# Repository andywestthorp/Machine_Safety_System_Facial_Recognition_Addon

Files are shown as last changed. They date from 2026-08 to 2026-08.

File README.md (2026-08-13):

# DTFace — Facial Recognition & Enrollment System

A dual-mode Raspberry Pi & Flask facial recognition system designed for real-time verification and web-based enrollment. It uses 128-dimensional face embedding vectors cached locally for high-speed matching, integrates with a backend MySQL/PHP database, and communicates via USB Serial with external hardware (ESP8266/ESP32).

To help explain things, please take a look at the following Youtube videos:

* **New feature**: (https://www.youtube.com/watch?v=8xTHW9tI40U) — Proof of concept
* **Existing system in workshop**: (https://www.youtube.com/watch?v=OMUBlsAB1YI) — The current RFID system.
* **Management console**: (https://www.youtube.com/watch?v=gfuSRVSx0mU) — The simple management console.

## 🏗️ Architecture Overview

```text
 [ ESP32-S3-CAM ]  --(HTTP POST JPEG)-->  [ Flask Server (Port 5000) ]  --(JSON Vector)-->  [ PHP / MySQL Database ]
 (Display + Ring)                        (face_recognition / dlib)                         (face_vectors.php)

```

1. **ESP32-S3-CAM:** Captures frame via camera feed, displays live UI on GC9A01 screen, and triggers light ring flash on snapshot button press.
2. **Flask Processing Engine:** Handles face detection, extracts 128-D face encodings, and matches faces against an in-memory memory cache.
3. **Web Dashboard:** Served directly by Flask. Allows admins to search members, activate target **Enrollment Mode**, or delete facial vectors.
4. **PHP API / Database:** Acts as the persistent backend store for member profiles and 128-D vector arrays.

---

## 🛠️ Hardware Requirements

* **Board:** GOOUUU ESP32-S3-CAM
* **Display:** GC9A01 240x240 Round LCD (SPI interface)
* **Lighting:** 24-LED WS2812B NeoPixel Ring Light
* **Trigger:** Momentary Push Button

### Pin Mapping

| Component | Function | ESP32-S3 GPIO |
| --- | --- | --- |
| **Snap Button** | Input (Pull-Up) | `GPIO 2` |
| **NeoPixel Ring** | D-In | `GPIO 1` |
| **GC9A01 Display** | SCLK | `GPIO 48` |
|  | MOSI (SDA) | `GPIO 47` |
|  | DC | `GPIO 21` |
|  | CS | `GPIO 45` |
|  | RST | `GPIO 19` |
| **Serial Comms** | TX | Connect to RX of ESP8266 |
|  | RX | Connect to TX of ESP8266 |
|  | GND | Connect to GND of ESP8266 |

> ⚠️ **Note:** Ensure the button is wired between `GPIO 2` and `GND`. Also make sure that you can disconnect the two ESP devices (I used an RJ11 cable and two RJ11 sockets).

---

## 💻 Software Prerequisites

### 1. Python Server Environment

* Python 3.8+
* `face_recognition` (`dlib`)
* `OpenCV` (`opencv-python`)
* `Flask`
* `requests`
* `numpy`

### 2. ESP32 Arduino Dependencies

* **Libraries:** `LovyanGFX`, `Adafruit_NeoPixel`, `ArduinoJson`, `HTTPClient`, `WiFi`
* **Board Package:** ESP32 by Espressif Systems (v2.x or v3.x)

---

## 🚀 Getting Started

### 1. Configure and Run the Flask Server

1. Install required dependencies:
```bash
pip install flask opencv-python face_recognition numpy requests

```

2. Update `API_URL` inside `app.py` to point to your PHP backend endpoint.
3. Start the Flask application:
```bash
python app.py

```

4. Access the web dashboard by navigating to `http://<YOUR_SERVER_IP>:5000/`.

### 2. Flash the ESP32-S3

1. Open `ESP32-S3-Cam-Screen.ino` in Arduino IDE.
2. Update Wi-Fi and Server credentials:
```cpp
const char* WIFI_SSID  = "YOUR_WIFI_NAME";      
const char* WIFI_PASS  = "YOUR_WIFI_PASSWORD";  
const char* SERVER_URL = "http://<YOUR_SERVER_IP>:5000/upload";

```

3. Set tools configuration in Arduino IDE:
* **Board:** `ESP32S3 Dev Module`
* **PSRAM:** `OPI PSRAM`
* **Partition Scheme:** `Huge APP (3MB No OTA/1MB SPIFFS)`

4. Upload the code to your ESP32-S3.

---

## 📖 User Workflow

### A. Verification Mode (Default)

1. Point the camera at a person.
2. Press the **Snap Button**.
3. The NeoPixel ring flashes warm white for exposure.
4. The server runs facial recognition against cached encodings:
* 🟢 **Match:** Display shows green screen with Name & RFID + Green LED Ring.
* 🔴 **No Match:** Display shows red screen + Red LED Ring.

### B. Enrolling a Person

1. Open `http://<SERVER_IP>:5000/` on a web browser.
2. Search for a name/surname in the filtered search bar.
3. Click **Enroll**. The web banner switches to active **Enrollment Mode**.
4. Direct the target person to face the ESP32-S3 camera and press the **Snap Button**.
5. The face vector is generated, submitted to the PHP API, and added instantly to the active server cache.

### C. Deleting a Profile Vector

1. Search for an enrolled user on the web dashboard.
2. Click **Delete**.
3. Confirm prompt to clear the vector from the database and invalidate local server cache.

---

## 🔒 Security & Performance Notes

* **Vector Match Tolerance:** `DISTANCE_THRESHOLD` is set to `0.55` in `app.py` for optimal balance between accuracy and false positives.
* **Camera Optimization:** Mirroring (`hmirror`) and vertical flipping (`vflip`) are active to present a natural mirror-like UI experience on the GC9A01 display.

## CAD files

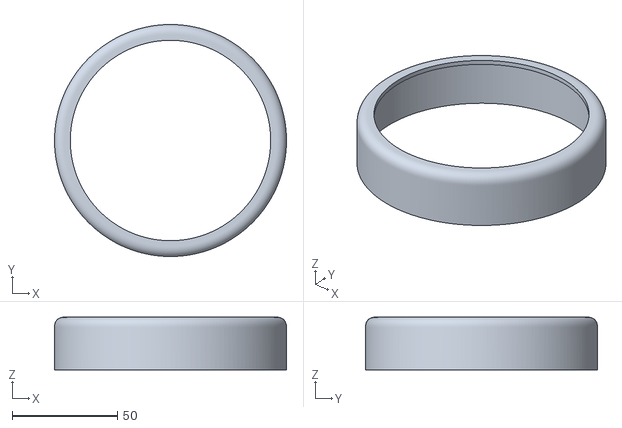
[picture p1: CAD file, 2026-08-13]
enclosure/Side_Cover.stl
110.0 x 110.0 x 25.0

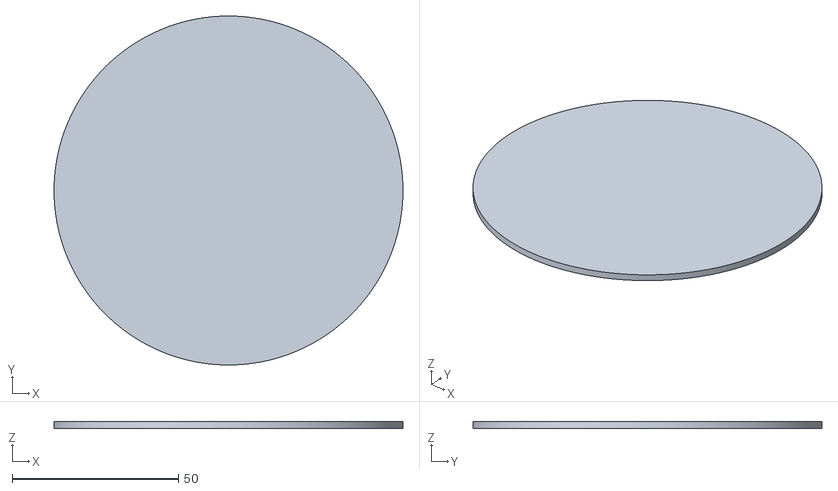
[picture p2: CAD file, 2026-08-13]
enclosure/Clear-Window.stl
105.0 x 105.0 x 2.00

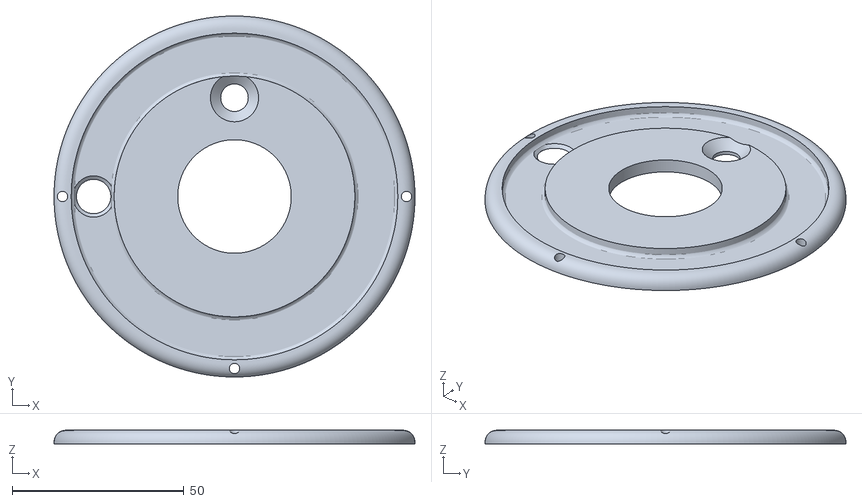
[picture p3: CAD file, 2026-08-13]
enclosure/Front_Insert.stl
105.0 x 105.0 x 4.00

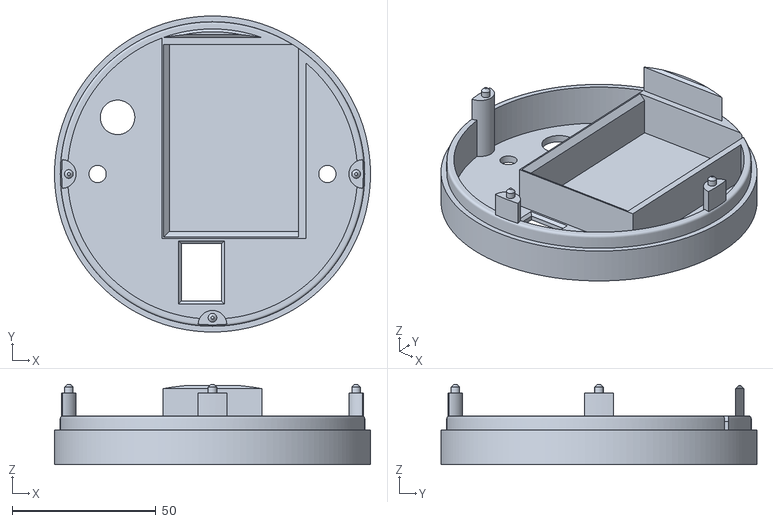
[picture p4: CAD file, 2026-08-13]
enclosure/Back.stl
110.0 x 110.0 x 28.0

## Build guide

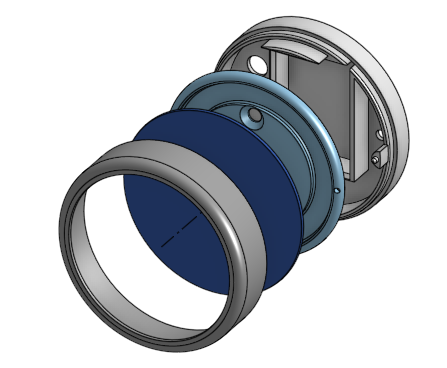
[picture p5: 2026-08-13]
enclosure/assembly(exploded).png

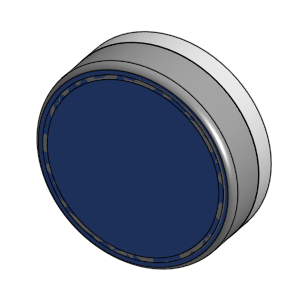
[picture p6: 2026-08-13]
enclosure/assembly.png

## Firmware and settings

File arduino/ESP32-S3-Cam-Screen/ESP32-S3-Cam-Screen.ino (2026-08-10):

// ====================================================================================
// This code is for an ESP32-S3-CAM - Not just an ESP32CAM - as we need more GPIO lines
// ====================================================================================

#include "esp_camera.h"
#include <WiFi.h>
#include <HTTPClient.h>
#define LGFX_USE_V1
#include <LovyanGFX.hpp>
#include <ArduinoJson.h>
#include <Adafruit_NeoPixel.h>

// ============================================================================
// 0. WI-FI & FLASK SERVER CONFIGURATION
// ============================================================================

const char* WIFI_SSID     = "<your_wifi>";      
const char* WIFI_PASS     = "<your_password>";  
const char* SERVER_URL    = "http://<server_address>:5000/upload"; 

#define BUTTON_PIN 2

// 💡 NEOPIXEL RING LIGHT CONFIGURATION
#define LED_PIN     1     // GPIO 1 is free and suitable!
#define NUM_LEDS   24     // Your 24-LED ring

Adafruit_NeoPixel ring(NUM_LEDS, LED_PIN, NEO_GRB + NEO_KHZ800);

// Helper functions for light effects
void setRingColor(uint8_t r, uint8_t g, uint8_t b, uint8_t brightness = 50) {
  ring.setBrightness(brightness); // Keep brightness capped to prevent brownout
  for (int i = 0; i < NUM_LEDS; i++) {
    ring.setPixelColor(i, ring.Color(r, g, b));
  }
  ring.show();
}

void turnOffRing() {
  ring.clear();
  ring.show();
}

// ============================================================================
// 1. LOVYANGFX DISPLAY CONFIGURATION (GC9A01 Round Display)
// ============================================================================
class LGFX : public lgfx::LGFX_Device {
  lgfx::Panel_GC9A01 _panel_instance;
  lgfx::Bus_SPI _bus_instance;

public:
  LGFX() {
    {  // Configure SPI Bus
      auto cfg = _bus_instance.config();
      cfg.spi_host = SPI2_HOST;  // FSPI / SPI2
      cfg.spi_mode = 0;
      cfg.freq_write = 20000000;  // 20MHz SPI Clock speed
      cfg.pin_sclk = 48;          // SCLK / CLK (Display)
      cfg.pin_mosi = 47;          // MOSI / SDA / DIN (Display)
      cfg.pin_miso = -1;          // Unused
      cfg.pin_dc = 21;            // DC / RS (Display)
      _bus_instance.config(cfg);
      _panel_instance.setBus(&_bus_instance);
    }
    {  // Configure GC9A01 Panel Settings
      auto cfg = _panel_instance.config();
      cfg.pin_cs = 45;   // CS (Display)
      cfg.pin_rst = 19;  // RES / RST (Display)
      cfg.panel_width = 240;
      cfg.panel_height = 240;
      cfg.invert = true;  // GC9A01 panels require color inversion
      _panel_instance.config(cfg);
    }
    setPanel(&_panel_instance);
  }
};

LGFX lcd;

// ============================================================================
// 2. GOOUUU ESP32-S3-CAM PIN CONFIGURATION
// ============================================================================
#define PWDN_GPIO_NUM -1
#define RESET_GPIO_NUM -1
#define XCLK_GPIO_NUM 15
#define SIOD_GPIO_NUM 4
#define SIOC_GPIO_NUM 5

#define Y9_GPIO_NUM 16
#define Y8_GPIO_NUM 17
#define Y7_GPIO_NUM 18
#define Y6_GPIO_NUM 12
#define Y5_GPIO_NUM 10
#define Y4_GPIO_NUM 8
#define Y3_GPIO_NUM 9
#define Y2_GPIO_NUM 11
#define VSYNC_GPIO_NUM 6
#define HREF_GPIO_NUM 7
#define PCLK_GPIO_NUM 13

// ============================================================================
// 3. SETUP FUNCTION
// ============================================================================
void setup() {
  Serial.begin(115200);

  // Initialize NeoPixel Ring Light
  ring.begin();
  turnOffRing(); // Ensure LEDs are off at boot

  unsigned long startWait = millis();
  while (!Serial && (millis() - startWait < 4000)) {
    delay(10);
  }

  delay(2000);
  Serial.println("\n\n=====================================");
  Serial.println("= ESP32-S3 Face Recogniser (Aug 26) =");
  Serial.println("=====================================\n");
  
  pinMode(BUTTON_PIN, INPUT_PULLUP);

  // A. Initialize Screen
  lcd.init();
  lcd.setRotation(1);
  lcd.fillScreen(TFT_BLACK);
  lcd.setTextColor(TFT_WHITE, TFT_BLACK);
  lcd.setTextDatum(textdatum_t::middle_center);

  // B. Connect to Wi-Fi
  lcd.drawString("Connecting Wi-Fi...", 120, 120, 2);
  Serial.print("Connecting to Wi-Fi");

  WiFi.mode(WIFI_STA);
  WiFi.begin(WIFI_SSID, WIFI_PASS);

  unsigned long wifiStart = millis();
  while (WiFi.status() != WL_CONNECTED && millis() - wifiStart < 8000) {
    delay(500);
    Serial.print(".");
  }

  if (WiFi.status() == WL_CONNECTED) {
    Serial.println("\n✅ Wi-Fi Connected!");
    lcd.drawString(WiFi.localIP().toString().c_str(), 120, 120, 2);
    delay(1000);
  } else {
    Serial.println("\n⚠️ Wi-Fi Connection Timeout");
    lcd.drawString("No WiFi", 120, 120, 2);
    delay(1000);
  }

  // C. Camera Settings
  camera_config_t config;
  config.ledc_channel = LEDC_CHANNEL_0;
  config.ledc_timer   = LEDC_TIMER_0;
  config.pin_d0       = Y2_GPIO_NUM;
  config.pin_d1       = Y3_GPIO_NUM;
  config.pin_d2       = Y4_GPIO_NUM;
  config.pin_d3       = Y5_GPIO_NUM;
  config.pin_d4       = Y6_GPIO_NUM;
  config.pin_d5       = Y7_GPIO_NUM;
  config.pin_d6       = Y8_GPIO_NUM;
  config.pin_d7       = Y9_GPIO_NUM;
  config.pin_xclk     = XCLK_GPIO_NUM;
  config.pin_pclk     = PCLK_GPIO_NUM;
  config.pin_vsync    = VSYNC_GPIO_NUM;
  config.pin_href     = HREF_GPIO_NUM;
  config.pin_sccb_sda = SIOD_GPIO_NUM;
  config.pin_sccb_scl = SIOC_GPIO_NUM;
  config.pin_pwdn     = PWDN_GPIO_NUM;
  config.pin_reset    = RESET_GPIO_NUM;
  
  config.xclk_freq_hz = 16000000;         
  config.pixel_format = PIXFORMAT_JPEG;   
  config.frame_size   = FRAMESIZE_QVGA;   
  config.fb_location  = CAMERA_FB_IN_PSRAM;
  config.jpeg_quality = 12;
  config.fb_count     = 2;                

  // D. Initialize Camera
  esp_err_t err = esp_camera_init(&config);
  if (err != ESP_OK) {
    Serial.printf("❌ Camera init failed: 0x%x\n", err);
    return;
  }

  sensor_t * s = esp_camera_sensor_get();
  if (s != NULL) {
    s->set_vflip(s, 1); 
    s->set_hmirror(s, 1); 
    s->set_brightness(s, 1);   
    s->set_contrast(s, 1);     
    s->set_aec2(s, 1);         
    s->set_ae_level(s, 1);     
  }
  lcd.fillScreen(TFT_BLACK);
}

// ============================================================================
// 4. BUTTON DEBOUNCE HELPER
// ============================================================================
bool isButtonPressed() {
  static unsigned long lastPressTime = 0;

  if (digitalRead(BUTTON_PIN) == LOW) {
    

    if (millis() - lastPressTime > 250) {
      lastPressTime = millis();
      return true;
    }
  }
  return false;
}

// ============================================================================
// 5. ANIMATION & HELPER FUNCTIONS
// ============================================================================
uint16_t dimColor(uint16_t color, float factor) {
  if (factor <= 0.0f) return TFT_BLACK;
  if (factor >= 1.0f) return color;

  uint8_t r = (color >> 11) & 0x1F;
  uint8_t g = (color >> 5) & 0x3F;
  uint8_t b = color & 0x1F;

  r = (uint8_t)(r * factor);
  g = (uint8_t)(g * factor);
  b = (uint8_t)(b * factor);

  return (r << 11) | (g << 5) | b;
}

void drawDotSpinner(uint16_t primaryColor) {
  static int step = 0;
  int centerX = 120, centerY = 120;
  int orbitRadius = 100;
  int maxRadius = 10;

  for (int i = 0; i < 8; i++) {
    int dotAngle = (i * 45) % 360;
    float rad = dotAngle * 0.0174533f;

    int x = centerX + sin(rad) * orbitRadius;
    int y = centerY - cos(rad) * orbitRadius;

    int distanceBehind = (step - i + 8) % 8;
    float brightness = 0.0f;
    int dotRadius = 0;

    if (distanceBehind == 0) {
      brightness = 1.0f;
      dotRadius = maxRadius;
    } else if (distanceBehind <= 4) {
      brightness = 1.0f - (distanceBehind * 0.22f);
      dotRadius = maxRadius - (distanceBehind * 2);
    } else {
      brightness = 0.0f;
      dotRadius = 0;
    }

    lcd.fillCircle(x, y, maxRadius + 1, TFT_BLACK);

    if (dotRadius > 0 && brightness > 0.0f) {
      uint16_t blendedColor = dimColor(primaryColor, brightness);
      lcd.fillCircle(x, y, dotRadius, blendedColor);
    }
  }

  step = (step + 1) % 8;
}

// ============================================================================
// 6. UPLOAD FUNCTION (POST TO FLASK)
// ============================================================================
void uploadImageToFlask(camera_fb_t * fb) {
  if (WiFi.status() != WL_CONNECTED) {
    Serial.println("❌ Wi-Fi Disconnected!");
    turnOffRing();
    return;
  }

  HTTPClient http;
  http.begin(SERVER_URL);
  http.addHeader("Content-Type", "image/jpeg");

  unsigned long startTime = millis();

  // Send binary image frame via HTTP POST
  int httpResponseCode = http.POST(fb->buf, fb->len);

  // Keep rendering dot spinner while HTTP upload progresses
  while (millis() - startTime < 1500) {
    drawDotSpinner(TFT_GREEN);
    delay(30);
  }

  if (httpResponseCode > 0) {
    Serial.printf("✅ Image Uploaded! Server Response Code: %d\n", httpResponseCode);
    
    String responseText = http.getString();
    //Serial.println("📩 Raw Server Response: " + responseText);
// message = f"Face Recognised, RFID= {rfid}\n"
    StaticJsonDocument<512> doc;
    DeserializationError error = deserializeJson(doc, responseText);

    if (!error) {
      bool recognized = doc["recognized"] | false;

      if (recognized) {
        const char* name = doc["results"][0]["name"];
        const char* rfid = doc["results"][0]["rfid"];
        Serial.printf("Face Recognised, RFID=%s\n", rfid);
        
        // 💡 LIGHT RING: Solid Green on match!
        setRingColor(0, 255, 0, 80);

        // 📺 Draw Match Badge on Screen
        lcd.fillScreen(TFT_GREEN);
        lcd.setTextColor(TFT_BLACK, TFT_GREEN);
        lcd.setTextDatum(textdatum_t::middle_center); 
        
        lcd.drawString("MATCH FOUND!", 120, 70, 4);
        lcd.drawString(name, 120, 120, 4);
        lcd.drawString(rfid, 120, 160, 2);

      } else {
        // 💡 LIGHT RING: Solid Red on no match
        setRingColor(255, 0, 0, 80);

        // 📺 Draw Unknown Badge on Screen
        lcd.fillScreen(TFT_RED);
        lcd.setTextColor(TFT_WHITE, TFT_RED);
        lcd.setTextDatum(textdatum_t::middle_center);
        
        lcd.drawString("NO MATCH", 120, 100, 4);
        lcd.drawString("Unknown Person", 120, 140, 2);
      }

    } else {
      setRingColor(255, 255, 0, 50); // Yellow on bad JSON
      lcd.fillCircle(120, 120, 35, TFT_YELLOW);
      lcd.setTextColor(TFT_BLACK, TFT_YELLOW);
      lcd.drawString("BAD JSON", 120, 120, 2);
    }

  } else {
    setRingColor(255, 0, 0, 80);
    lcd.fillCircle(120, 120, 35, TFT_RED);
    lcd.setTextColor(TFT_WHITE, TFT_RED);
    lcd.drawString("ERROR", 120, 120, 4);
  }

  http.end();
  delay(2500); // Hold result on screen & ring light
  turnOffRing(); // Turn light back off before resuming stream
}

// ============================================================================
// 7. MAIN STREAMING & CAPTURE LOOP
// ============================================================================
void loop() {
  // 1. Capture live camera feed
  camera_fb_t *fb = esp_camera_fb_get();
  if (!fb) return;

  // Render JPEG frame to LovyanGFX display
  lcd.drawJpg(fb->buf, fb->len, 0, 0);

  // 2. Check for button snap
  if (isButtonPressed()) {
    Serial.println("📸 SNAP! Button pressed - Sending image...");

    // 💡 FLASH LIGHT: Turn on Natural Warm White (255, 190, 110) at ~20% brightness
    setRingColor(255, 190, 110, 50); 
    delay(100); // Brief pause to let camera exposure adapt

    // Free live stream frame and grab a fresh, well-lit snapshot
    esp_camera_fb_return(fb);
    fb = esp_camera_fb_get();

    // Overlay status text
    lcd.setTextColor(TFT_CYAN, TFT_BLACK);
    lcd.drawString("CHECKING...", 120, 120, 2);

    // Perform HTTP POST to Flask
    uploadImageToFlask(fb);
  }

  esp_camera_fb_return(fb);
}

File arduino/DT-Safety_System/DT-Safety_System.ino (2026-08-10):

/**************************************************************************
  Wiring:

  TFT-LCD      NodeMCU
  ====================
  VCC  ------  3.3v
  GND  ------` GND
  CS   ------  GPIO 15 (Pin D8)
  RST  ------  RST
  A0   ------  GPIO 2  (Pin D4)
  MOSI ------  GPIO 13 (Pin D7)
  SCK  ------  GPIO 14 (Pin D5)
  LED  ------  3.3v

  Screen size:  128 x 160 pixels

  RFID Scanner    NodeMCU
  =======================
  3.3v  ----------  3.3v
  RST ------------  RST
  GND ------------  GND
  IRQ
  MISO  ----------- GPIO 12 (Pin D6)
  MOSI  ----------- GPIO 13 (Pin D7)
  SCK   ----------- GPIO 14 (Pin D5)
  SDA   ----------- GPIO 16 (Pin D0)

 **************************************************************************/

#include <Arduino.h>
#include <LittleFS.h>
// Scanner number and machine name
String Scanner = "DT-3";
String machine_name = "Hi! I am the Rexon Bandsaw BS10SA.";

// The TFT Details
#include <Adafruit_GFX.h>     // Core graphics library
#include <Adafruit_ST7735.h>  // Hardware-specific library for ST7735
#include <Fonts/FreeMonoBoldOblique12pt7b.h>
#include <Fonts/FreeSerif9pt7b.h>
#include "images.h"
#include <SPI.h>

#define TFT_CS 15
#define TFT_RST 16  // May cause trouble?
#define TFT_DC 2

Adafruit_ST7735 tft = Adafruit_ST7735(TFT_CS, TFT_DC, TFT_RST);

#define BLACK 0x0000
#define NAVY 0x000F
#define DARKGREEN 0x03E0
#define DARKCYAN 0x03EF
#define MAROON 0x7800
#define PURPLE 0x780F
#define OLIVE 0x7BE0
#define LIGHTGREY 0xC618
#define DARKGREY 0x7BEF
#define BLUE 0x001F
#define GREEN 0x07E0
#define CYAN 0x07FF
#define RED 0xF800
#define MAGENTA 0xF81F
#define YELLOW 0xFFE0
#define WHITE 0xFFFF
#define ORANGE 0xFD20
#define GREENYELLOW 0xAFE5
#define PINK 0xF81F

// The RFID Scanner details
#include <MFRC522.h>
constexpr uint8_t RST_PIN = D3;
constexpr uint8_t SS_PIN = D0;
MFRC522 rfid(SS_PIN, RST_PIN);

MFRC522::MIFARE_Key key;
String tag;

int blockNum = 2;
byte blockData[16] = { "DTSafety-Master" };
byte bufferLen = 18;
byte readBlockData[18];

MFRC522::StatusCode status;

// The buzzer:
int frequency = 2000;  // Specified in Hz
int buzzPin = D1;
int timeOn = 100;   // Specified in milliseconds
int timeOff = 100;  // Specified in milliseconds

// The WiFi & Secure HTTP details
#include <ESP8266WiFi.h>
#include <ESP8266WiFiMulti.h>
#include <ESP8266HTTPClient.h>
#include <WiFiClientSecure.h>
#include <WiFiUdp.h>

ESP8266WiFiMulti WiFiMulti;

#include <ESPAsyncTCP.h>
#include <ESPAsyncWebServer.h>

#define ELEGANTOTA_USE_ASYNC_WEBSERVER 1
#include <ElegantOTA.h>

AsyncWebServer server(80);

const char* ssid = "<SSID>";
const char* password = "<Password>";

// Main HTTPS Endpoint
const char* rfid_endpoint = "https://<address>/rfid.php";

String User_Key_Value = "";
String update_progress = "0%";
bool updating = false;

int WiFi_Connection_Attempts = 0;
boolean master_key_overide = false;

bool cycle_in_progress = false;

unsigned long previousMillis = 0;  // Stores last time WiFi check-in occurred
const long interval = 5 * 60000;   // Interval (5 minutes)

#define Cycle_Start_PIN 4        // Pulled LOW to activate relays
#define Cycle_in_progress_PIN 0  // HIGH at end of cycle
// Forward declaration of functions
void check_with_server(bool is_pi_source = false);

void setup() {
  // Power-on beep sequence
  bleep(1000, 100);
  bleep(2000, 100);
  bleep(3000, 100);

  SPI.begin();
  rfid.PCD_Init();
  delay(1000);
  Serial.begin(115200);
  Serial.println(F("**************************"));
  Serial.println(F("DT Safety System August 2026"));
  Serial.println(F("(New Facial detection features)"));
  Serial.println(F("**************************\n"));

  // Load persistent parameters from flash
  loadConfig();
  Serial.println(machine_name);

  Serial.println("Setting up pins");
  pinMode(Cycle_Start_PIN, OUTPUT);
  pinMode(Cycle_in_progress_PIN, INPUT_PULLUP);
  digitalWrite(Cycle_Start_PIN, HIGH);

  Serial.println("Starting Screen");
  tft.initR(INITR_BLACKTAB);
  tft.setRotation(1);
  tft.setFont(&FreeSerif9pt7b);
  Serial.println(F("TFT Initialized"));

  tft.setTextColor(BLACK);
  tft.fillScreen(WHITE);
  tft.setCursor(20, 25);
  tft.println("Machine Safety");
  tft.setCursor(50, 45);
  tft.println("System");

  tft.fillRect(65, 60, 30, 38, BLUE);
  tft.drawBitmap(65, 60, logo, 30, 38, 0xffff);

  Serial.println("Setting up WiFi");
  WiFi.mode(WIFI_STA);
  WiFiMulti.addAP(ssid, password);  // Register credentials with WiFiMulti

  while (WiFiMulti.run() != WL_CONNECTED && WiFi_Connection_Attempts < 10) {
    Serial.print("Connecting to WiFi attempt ");
    Serial.println(WiFi_Connection_Attempts);
    delay(500);
    WiFi_Connection_Attempts++;
  }

  if (WiFiMulti.run() != WL_CONNECTED) {
    Serial.println("No Connection - Master Key Mode");
    master_key_overide = true;
  }

  // Network Details
  IPAddress ip = WiFi.localIP();
  String ipStr = ip.toString();

  Serial.println("");
  Serial.println("==================================");
  Serial.print("Connected to WiFi! IP address: ");
  Serial.println(ipStr);
  Serial.print("Web Console available at: http://");
  Serial.println(ipStr);
  Serial.println("==================================");

  // Print IP to TFT Screen
  tft.setCursor(25, 120);
  tft.println(ipStr);
  delay(2000);

  // ----------------------------------------------------------------
  // WEB SERVER ROUTE DEFINITIONS (Single Initialization Block)
  // ----------------------------------------------------------------

  // 1. Web Console Dashboard
  server.on("/", HTTP_GET, [](AsyncWebServerRequest* request) {
    String ipStr = WiFi.localIP().toString();
    int rssi = WiFi.RSSI();
    String macStr = WiFi.macAddress();

    String html = "<!DOCTYPE html><html><head><title>Machine Safety Console</title>";
    html += "<meta name='viewport' content='width=device-width, initial-scale=1'>";
    html += "<style>body{font-family:Arial;margin:20px;max-width:500px;} ";
    html += "input[type=text]{width:100%;padding:8px;margin:8px 0;box-sizing:border-box;} ";
    html += "input[type=submit]{background:#008CBA;color:white;padding:10px;border:none;width:100%;cursor:pointer;} ";
    html += ".card{background:#f2f2f2;padding:20px;border-radius:8px;margin-bottom:15px;}</style></head><body>";

    html += "<h2>Safety System Console</h2>";

    // Status Card
    html += "<div class='card'>";
    html += "<h3>Network Information</h3>";
    html += "<p><strong>IP Address:</strong> " + ipStr + "</p>";
    html += "<p><strong>Signal Strength (RSSI):</strong> " + String(rssi) + " dBm</p>";
    html += "<p><strong>MAC Address:</strong> " + macStr + "</p>";
    html += "</div>";
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

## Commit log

2026-07-26 Refactor face verification logic and DB config
    Updated database connection parameters and improved face recognition logic. Adjusted frame processing and bounding box rendering for better performance.
2026-08-10 Fix enclosure link in README
    Updated the enclosure link in the README to include render mode and UI state parameters.
2026-08-10 Fix enclosure CAD model link in README
    Updated the OnShape CAD Model link for the enclosure.
2026-08-10 Fix formatting for Trigger Switch description in README
2026-08-10 Add initial temp placeholder to ESP32-S3-Cam-Screen.ino
2026-08-10 Add wiring and setup details for DT Safety System
2026-08-10 Initial commit for ESP32-S3-CAM project
